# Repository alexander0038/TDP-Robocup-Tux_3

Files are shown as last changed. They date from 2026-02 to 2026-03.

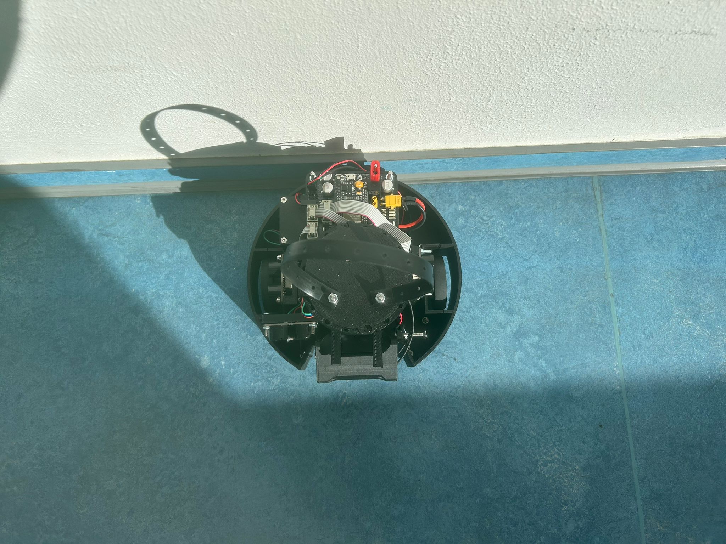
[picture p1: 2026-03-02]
Hardware/Robot pictures/Robot_picture_8.png

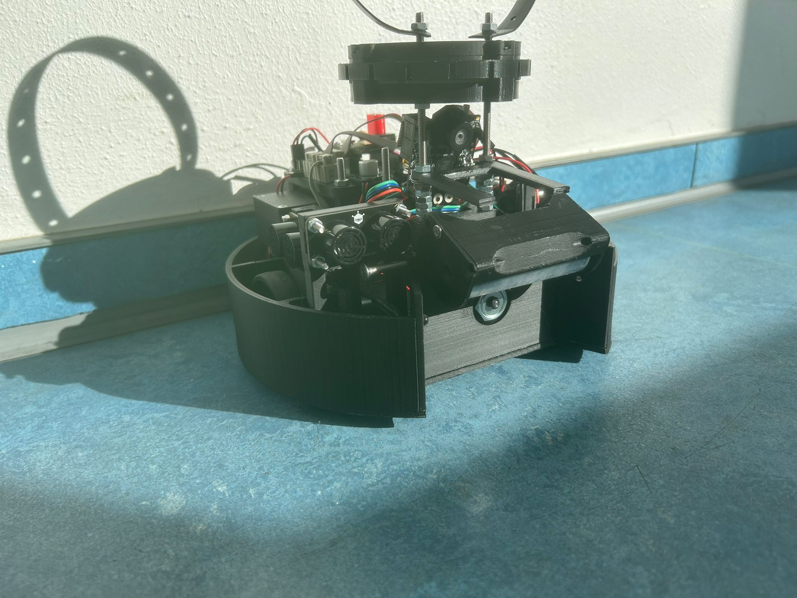
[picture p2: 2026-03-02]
Hardware/Robot pictures/Robot_picture_7.png

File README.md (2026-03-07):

# TEAM TUX_3 ROBOCUP PAGE

#### Email: tux3.gr@protonmail.com
#### Youtube: https://www.youtube.com/@Tux_3_gr

## General information about us:
We are Tux_3, a team from Rahden, a small town in North Rhine-Westphalia near Bielefeld. Our team consists of **Alexander Belov (Software, Team Captain)**, **Toni Schürmann (Software)**, **Max Harting (Hardware)** and **Henning Baumgartner (Hardware)**. We compete in the RoboCupJunior Soccer Entry League for the second time.

During our first time competing in RoboCup, we were separate teams: Tux_3 (Alexander and Henning) and Tux_4 (Toni and Max). Both teams made it into the top 5 and qualified for the German Open in Nuremberg. The competition in Nuremberg had strong opponents, so unfortunately we did not qualify for the European Championship.

However, these losses and wins did not make us lose motivation; instead, we merged into one team. We learned how to work together, and soon we managed to achieve second place in the Berlin qualification. Now we are preparing for the German Open in Cologne, hoping we can qualify for the European Championship.

---

### Where to find what:

#### Hardware:
- General information: `/Hardware/README.md`
- Chassis: `/Hardware/Chassis Pictures`
- Robot pictures: `/Hardware/Robot pictures`
- CAD programs: `/Hardware/CAD programs`

#### Software:
-  General information: `/software/README.md`
-  Program: `/software/Main`
-  Software for Sensors: `/software/Sensors`
-  Flowchart: `/software/Flowchart.png`
-  Strategy: `/software/Strategy.md`

#### Team:
- Team Description Paper: `/Tux_3_GO2026_tdp.pdf`
- Team picture: `/Tux_3.png`
- Team poster: `/Tux_3_GO2026_poster.pdf`

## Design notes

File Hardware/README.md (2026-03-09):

# Tux_3 Hardware Overview

This document describes the hardware architecture of the **Tux_3** RoboCupJunior Entry League robot.

## Mechanical Design

The chassis of Tux_3 is fully **3D-printed** and designed in **Autodesk Fusion**.  
It was built to be compact, stable, and easy to maintain.

Compared to the **LEGO-based robot used in the 2025 season**, the custom chassis provides significantly improved stability and durability.

## Drive System

Tux_3 uses a **two-motor drive system**.

- Pololu **25Dx48L MP 12V motors**
- Direct wheel mounting
- **Infineon IFX9201SG motor drivers**

This configuration provides strong acceleration, reliable turning, and a simple mechanical setup.

## Ball Handling and Kicking

### Dribbler

- Powered by a **GA16Y-050-CE motor**
- Maintains ball contact while driving

### Kicker

- Controlled by an **Infineon BTN8982TA** driver
- Mechanically aligned with the dribbler for consistent shots

## Sensors

Tux_3 uses several sensors for perception and navigation.

- **Vishay TSSP6038TR IR sensors** — ball detection  
- **CMPS14 compass** — orientation  
- **Pixy2 camera** — goal detection  
- **Light barrier** — ball possession detection  
- **DFRobot URM09** — distance measurement and wall detection

All sensors are integrated into the chassis to ensure stable readings.

## Electronics

The robot is controlled by an **ESP32 microcontroller**.

- **Infineon IFX9201SG** drivers control the drive motors
- **Infineon BTN8982TA** controls the kicker

The electronics layout is optimized for short cable paths and quick maintenance during competitions.

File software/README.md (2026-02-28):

# Software Overview — Tux_3

This folder contains the complete software for the Tux_3 RoboCupJunior Entry League robot.

## Architecture

The software is structured into the following modules:

- **Main** — Main control loop and initialization
- **Sensors** — Handles all sensor reading (DFRobot_URM09, compass)
- **Strategy** — High-level decision logic (attack/search/rescue)
  **→ Flowchart**

The ESP32 runs a main loop with approx. 100 Hz frequency. Within this loop:
1. Sensors are updated
2. State decisions are evaluated
3. Movement commands executed

## Dependencies

- CoRoSoN Software (https://github.com/ItzJannis/CoRoSoN-Package_Draft)
- ESP32 Arduino Core
- Pixy2 library
- Motor driver interfaces

## How to Run

1. Open in Arduino IDE
2. Select ESP32 board
3. Upload `main.ino`

## Logic Summary

The software implements a state-based decision system:
- **GET_BALL**
- **SEARCH_FOR_ENEMY_GOAL**
- **TURN_TO_ENEMY_GOAL**
- **DRIVE_TOWARDS_GOAL**
- **RESCUE**

Each state has its own behavior function (see strategy.cpp).

## Example Code Snippets

```cpp
if (irRing.BallSeen) {
    currentState = GET_BALL;
}

if (stuck) {
    currentState = RESCUE;
}

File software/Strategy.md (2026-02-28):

# Tux_3 — Strategy Overview

This document describes the high-level strategy and decision-making system of Team Tux_3's RoboCupJunior Soccer Entry League robot. It explains how the robot selects actions during a match, reacts to dynamic game conditions, and implements basic tactical behaviors.

---

## 1. Control Architecture

The robot's software is organized around a **main control loop running at approximately 100 Hz**, combined with modular tasks for:

- Sensor data acquisition  
- Motion control  
- Decision-making and tactical strategy  
- Rescue routines (stuck detection and recovery)

The strategy module is responsible for deciding the robot's behavior based on sensor inputs and match conditions.

---

## 2. High-Level States

The robot operates according to a **state-based system**, switching between the following main states:

1. **GET_BALL**  
   - The robot searches for the ball using infrared sensors (TSSP6038TR).  
   - If the ball is detected, the roboter will drive towards it.
  
2. **BACK_TO_OWN_GOAL**
   - If the robot doesn't see the ball, it turns to towards the enemy goal and quickly drives backwards.
  
3. **SEACH_FOR_ENEMY_GOAL**
   - The robot searches for the goal, using the Pixy camera.

4. **TURN_TO_ENEMY_GOAL**  
   - When the robot detects the goal: turn towards it.

5. **DRIVE_TOWARDS_GOAL**  
   - If the robot is turned directly to the goal, it drives forward.
   - If the robot isn't directly turned toward the goal it uses the Ultrasonic Sensors (DFRobot_URM09) to correct itself to the correct direction.

6. **RESCUE**  
   - If the robot detects that it is stuck (via sensor readings or lack of movement), a recovery routine is triggered.  
   - This includes reversing, turning, and repositioning to continue play.
  
---

## 3. Decision Flow

The robot continuously evaluates sensor inputs to determine:

- Ball detection status  
- Obstacle proximity and collisions  
- Robot orientation  
- Field boundaries  

Decisions are made in the following order:

1. Check if **stuck** → trigger RESCUE if necessary  
2. Ball not seen → switch to BACK_TO_OWN_GOAL
3. Detect ball → switch to GET_BALL
4. Check goal visibility → switch to SEARCH_FOR_ENEMY_GOAL  
5. Goal found → switch to  TURN_TO_ENEMY_GOAL
6. Directly turned to enemy goal → switch to DRIVE_TOWARDS_GOAL

This priority ensures the robot always reacts to the most critical situation first.

---

## 4. Sensor Integration

- **IR Ball Sensors (TSSP6038TR):** Primary detection of ball position  
- **Pixy2 Camera:** Confirmation of ball and goal position  
- **Compass (CMPS14):** Orientation stabilization for accurate approach and shooting  
- **Light barrier:** Detection of ball possession in the dribbler
- **Ultrasonic Sensor(DFRobot_URM09):** Detection of the distance 

The strategy module fuses these inputs to maintain reliable state transitions and tactical behavior.

---

## 5. Team Considerations

The strategy was designed to be:

- **Simple but effective**: Ideal for Entry League robots with limited processing power  
- **Robust**: Handles unexpected collisions and field dynamics  
- **Modular**: Easy to adjust parameters or add future tactics  

The state-based approach allows the robot to perform consistently in matches, while also making its behavior understandable to judges during interviews and poster presentations.

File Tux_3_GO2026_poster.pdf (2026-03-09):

\

\

\

\

The robot was collaboratively developed and built by all team members. The goal was to create a functional and competitive 1-vs-1 entry robot capable of autonomously collecting the ball, controlling it, and shooting it into the goal.

The system includes a curcit board, a ball sensor for object detection, two drive motors, three ultrasonic sensors for distance measurement, a dribbler for ball control, a PixyCam for goal detection, two lightbarriers for object detection and a kicker for precise shooting. A bill of materials for the main components can be found at the roboter description .

The construction process was carried out chronologically in several stages. First, the Chase and mounting brackets were manufactured using 3D printing. The material we are using for our robot is PLA+

. Afterwards, we installed the ball sensor, two ultrasonic sensors, the motors, two lightbarriers and the dribbler. Following our participation in the Berlin Open 2026, the system was further improved: a third ultrasonic sensor, a PixyCam, a kicker, and a new Chase were added to enhance overall performance.

These were the key decisions we made during the development of our robot:
- A front-facing \_/-shaped opening improves ball intake and enables faster and more stable ball control through the dribbler.
- The retrofitted kicker addresses previously identified weaknesses in goal finishing and now allows for direct and controlled shooting.
- Two laterally positioned ultrasonic sensors ensure more precise alignment with the opponent’s goal and support stable driving direction.

The total development and construction time was approximately ten months, the overall cost of the robot amounts to €310, and we used the programming language C++ for programming.

We are four students from the Gymnasium Rahden, a small town in North Rhine-Westphalia near Bielefeld. We go to two different classes. Despite this separation at school, we are united by a close friendship and a shared interest in robotics. Almost two years ago, we joined our school’s robotics club. Since then, robotics has become an integral part of our lives, as we not only work in the club but also dedicate time on weekends and during holidays.

After an initial training phase in which we learned basic programming commands, we developed a strong interest in the practical implementation of technical concepts. During this time, we also learned a great deal about how to divide tasks effectively. As we progressed, we designed and programmed our first LEGO robot. In 2025, we initially competed as two separate teams at the Berlin Open. There, we achieved remarkable results: one team secured second place, while the other finished fourth. These performances qualified us for the German Open 2025, where we placed eighth and thirteenth.

In this school year, we expanded our skills particularly in the field of additive manufacturing (3D printing) as well as in hardware
development. In addition, we decided to merge our two teams in order to achieve a better overall result and to combine our strengths. This collaboration led to the construction of a high-performance robot for the Berlin Open 2026, where we once again achieved second place.

For the German Open 2026, we worked even harder compared to the previous year and are now aiming to qualify for the Europe Open in Vienna. Regardless of the outcome, we are proud of what we have already achieved.

drive motors:
Pololu 25Dx48L
MP 12V
(on both sides)

dribbler: GA16Y-050-CE

ultrasonic sensor:
DFRobot

_

URM09
(on both sides)

# TUX

_

3

# Team

From left to Right:
Alexander Belov (Software and Team Captain)
Toni Schürmann (Software)
Max Harting (Hardware)
Henning Baumgartner (Hardware)
Abstract | Hardware

# Software

# Our GitHub

# Training video

# Our YouTube

circuit board,
ball sensor and
compass sensor
(CoRoSoN-Kit)

camera:Pixy 2

lightbarrier (on both sides) | kicker: Solenoid

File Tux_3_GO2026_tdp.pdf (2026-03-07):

## TEAM DESCRIPTION PAPER

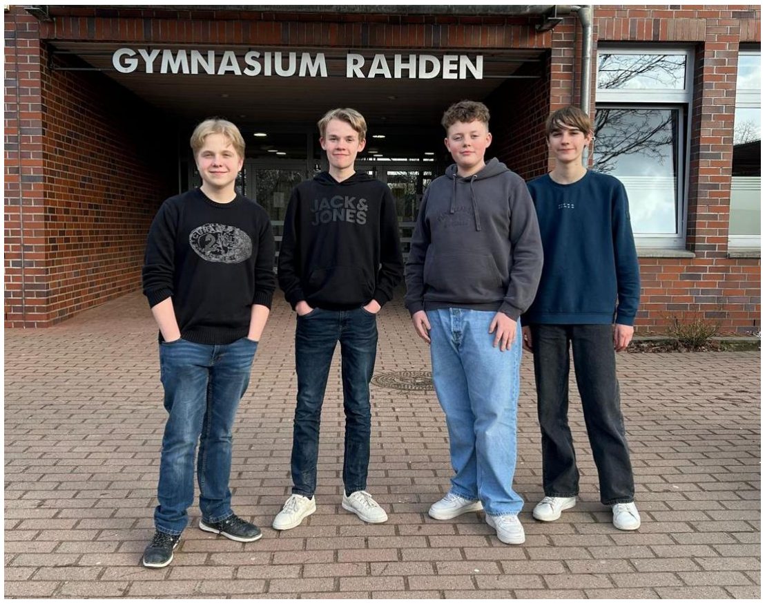
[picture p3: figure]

Team Tux_3 (from left to right: Alexander Belov (Team-Captain), Toni Schürmann, Max Harting, Henning Baumgartner)

Email: tux3.gr@protonmail.com

GitHub: https://github.com/alexander0038/TDP-Robocup-Tux_3/

Short Team Description

We, Tux_3, compete in the RoboCupJunior Soccer Entry League and were formed in 2026 by merging two previously independent teams.

In the 2025 season, the members competed separately as Tux_3 (Alexander and Henning) and Tux_4 (Max and Toni), both using LEGO-based robots. At the Berlin qualification tournament, Tux_3 achieved 2nd place and Tux_4 achieved 4th place. Both teams qualified for the German Championship in Nuremberg, where Tux_3 finished 8th (one match away from European qualification) and Tux_4 finished 13th.

In 2026, the two teams combined their experience and formed a single team under the name Tux_3, redesigning the robot with fully custom 3D-printed components. At the Berlin qualification tournament 2026, the new team achieved 2nd place.

Short Robot Description

The Tux_3 robot is a custom-built RoboCupJunior Entry League soccer robot designed for reliability, robustness, and continuous improvement. After competing with LEGO-based robots in 2025, the team fully redesigned the system for the 2026 season using custom 3D-printed components and a self-developed electronic architecture.

The robot is based on a two-motor differential drive system with integrated ball control and goal detection mechanisms. The overall design focuses on mechanical stability, precise ball handling, and structured decision-making during matches.

Hardware

Our hardware is based on the CoRoSoN-Kit (https://github.com/ItzJannis/CoRoSoN-Package_Draft). (https://github.com/ItzJannis/CoRoSoN-Package_Draft)

Drive System

- 2× Pololu 25Dx48L MP 12V motors
- Infineon IFX9201SG motor drivers

Ball Handling

- GA16Y-050-CE motor for dribbler
- Infineon BTN8982TA driver for kicker
- Light barrier for ball possession detection

Sensors

- Vishay TSSP6038TR infrared sensors for ball detection
- CMPS14 compass module for orientation stabilization
- Pixy2 camera for goal detection
- DFRobot_URM09 Ultrasonic sensors for distance measurement and wall correction

Electronics

- ESP32 microcontroller
- Custom wiring and structured component layout
- 3D-printed chassis designed in Autodesk Fusion

Software

The software is structured around a main control loop running on the ESP32. The system separates sensor acquisition, decision logic, and motor control into modular components. Our program is based on the CoRoSoN-Kit (https://github.com/ItzJannis/CoRoSoN-Package_Draft). (https://github.com/ItzJannis/CoRoSoN-Package_Draft)

Key characteristics:

- State-based decision logic:

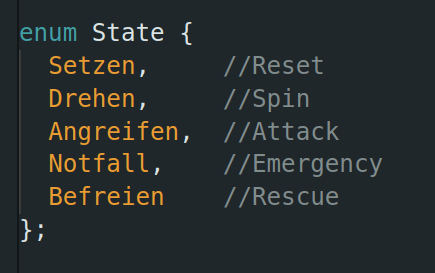
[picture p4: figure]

- Ball tracking using infrared sensors
- PID Control for motor control:

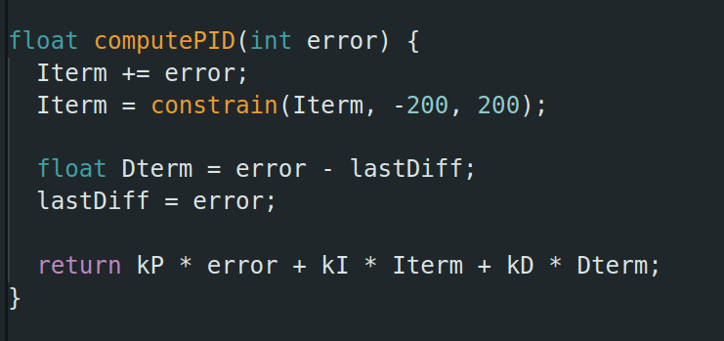
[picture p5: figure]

- Goal alignment using camera and compass
- Custom stuck-detection and recovery behavior:

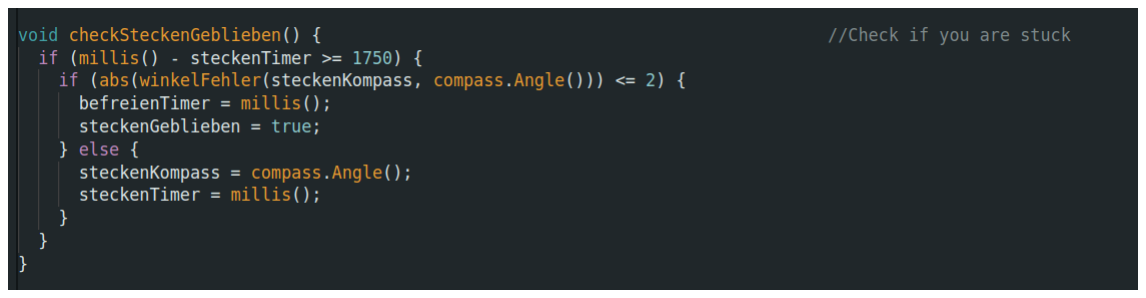
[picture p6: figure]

- Robot correction using ultrasonic feedback

The software was developed with a focus on maintainability, clarity, and match robustness.

Challenges During the Season

During the transition from LEGO to a fully custom 3D-printed robot, several challenges were encountered:

1. Mechanical Stability:
Early prototypes suffered from structural weaknesses and misalignment in the dribbler system.
2. Different Programming Languages:
We started with the programming language NXC, which translates to “Not exactly C”, and later switched to C/C++.
3. Sensor Calibration:
Reliable ball detection and consistent compass readings required extensive testing and calibration.
4. Drive Precision:
Achieving accurate turning and goal alignment without omni wheels required significant tuning of motor control.

Challenges Successfully Mastered

- Structural redesign improved mechanical robustness.
- Stable ball control was achieved through optimized dribbler positioning.
- Sensor placement and filtering significantly increased detection reliability.
- Stuck-detection logic improved match recovery performance.
- Team collaboration improved after merging two former teams into one unified structure.

These improvements led to a 2nd place finish at the 2026 Berlin qualification tournament.

Future Plans

For the next season, the team plans to:

- Compete in Robocup Junior Soccer Lightweight 1v1
- Learn more about the hardware
- Deepen our knowledge about programming
- Improve our ability to analyze and find mistakes in hardware and software faster
- Improve teamwork even further (if ’s even possible)

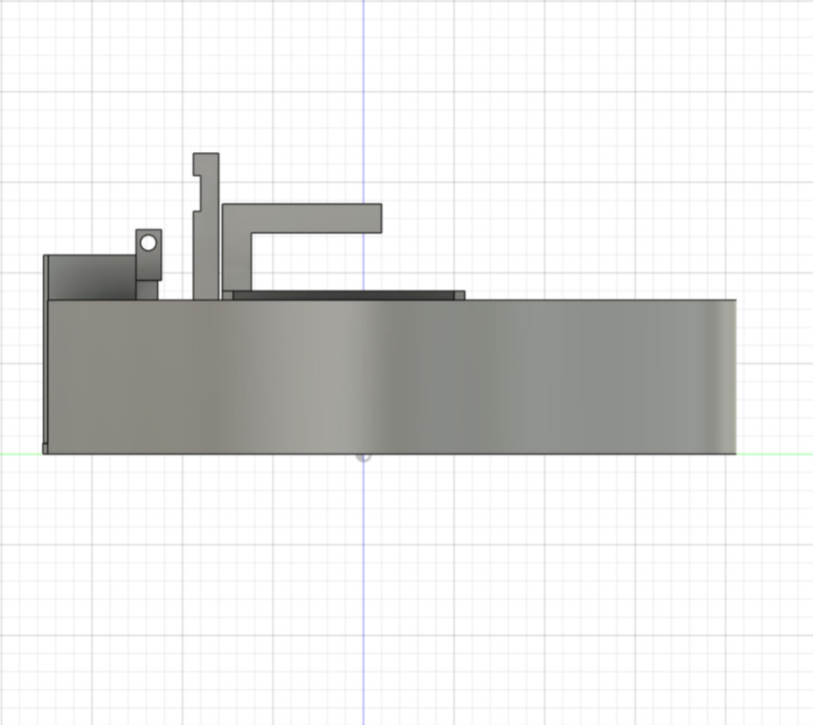
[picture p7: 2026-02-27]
Hardware/Chassis Pictures/Chassis_3.png

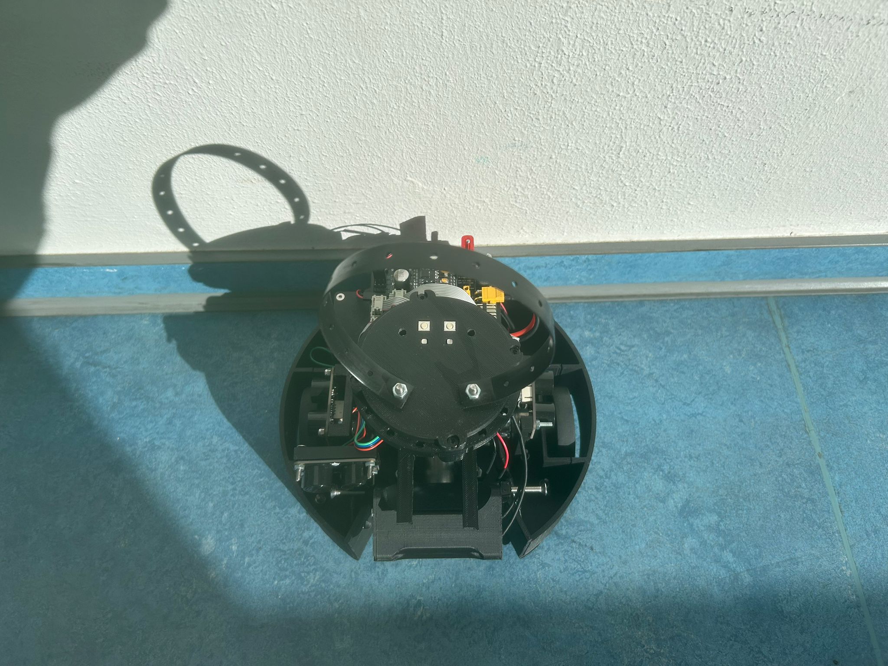
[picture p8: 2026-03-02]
Hardware/Robot pictures/Robot_picture_4.png

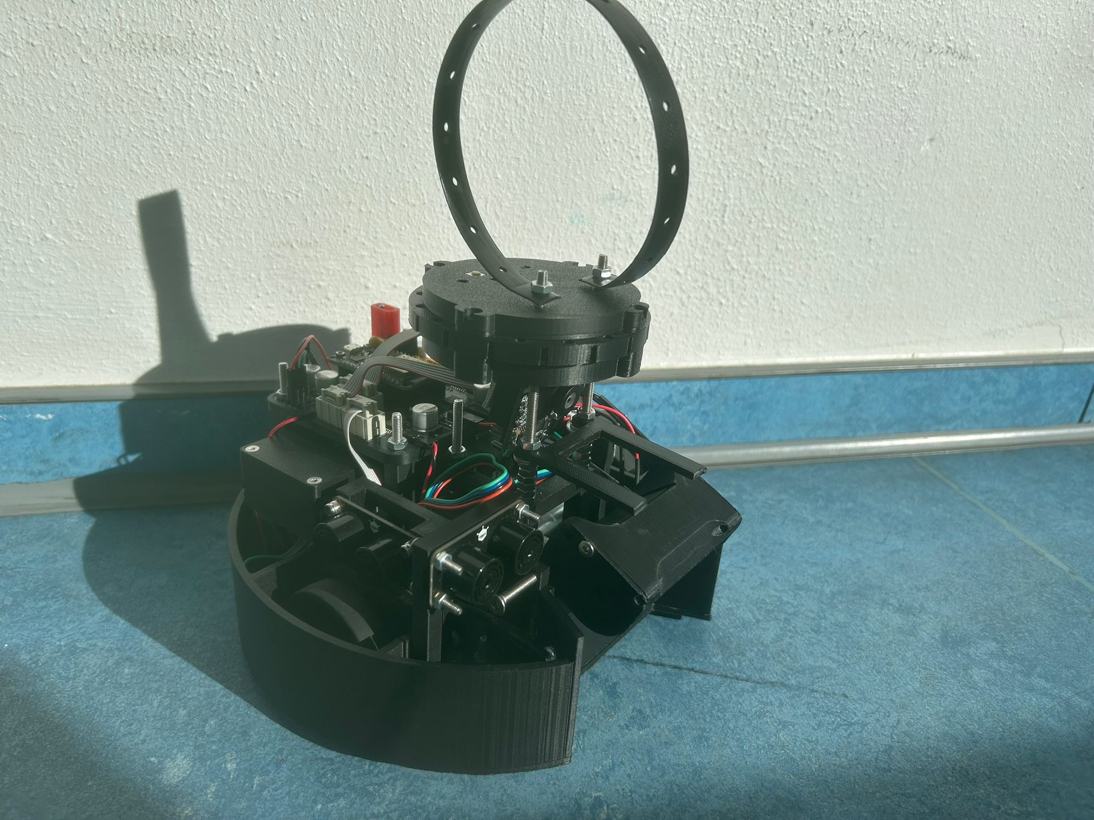
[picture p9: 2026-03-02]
Hardware/Robot pictures/Robot_picture_1.png

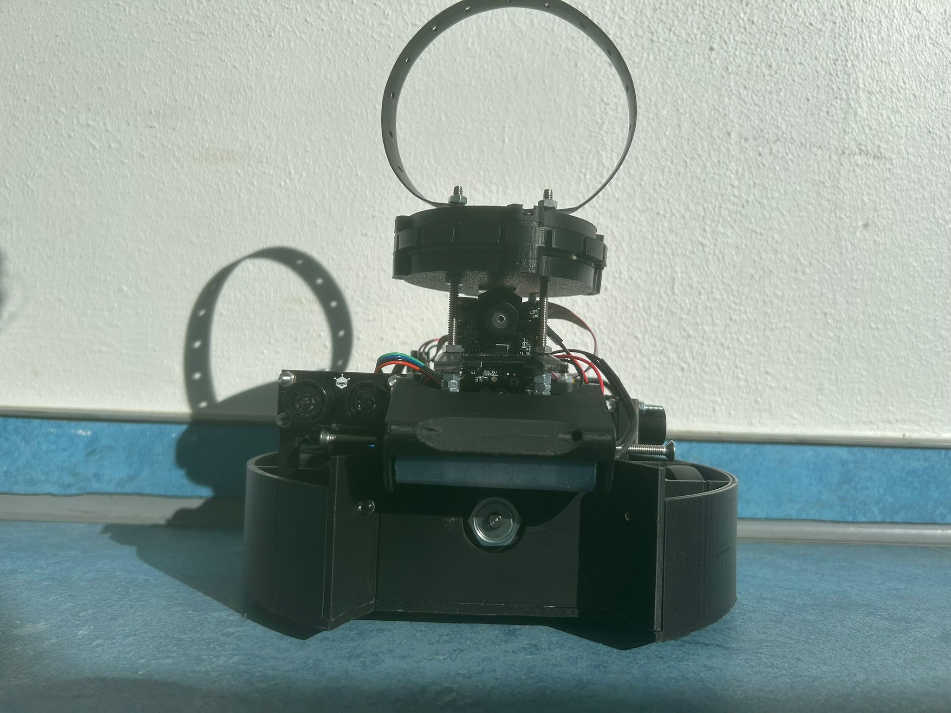
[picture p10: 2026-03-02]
Hardware/Robot pictures/Robot_picture_6.png

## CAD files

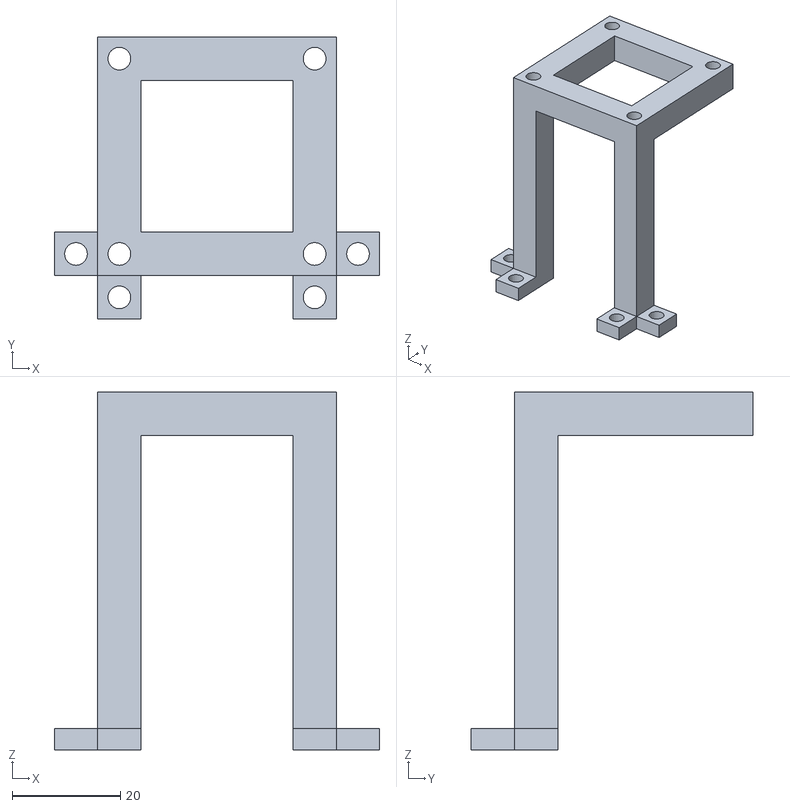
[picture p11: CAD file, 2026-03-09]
Hardware/CAD programs/Ballsensor mount.stl
60.0 x 52.0 x 66.0

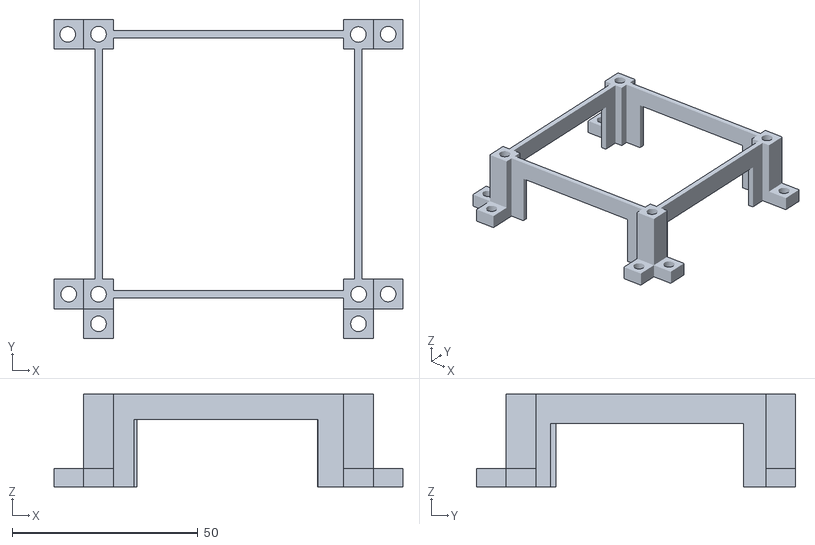
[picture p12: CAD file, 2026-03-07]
Hardware/CAD programs/Board mount.stl
94.0 x 86.0 x 25.0

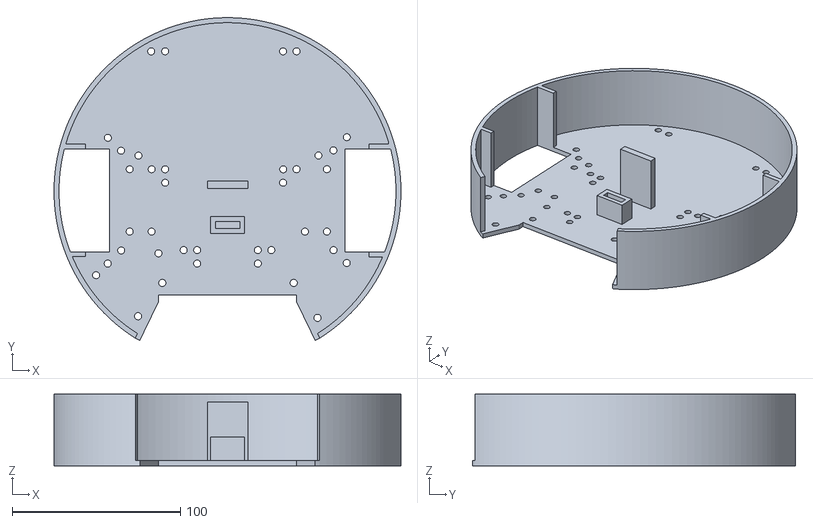
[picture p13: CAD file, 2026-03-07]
Hardware/CAD programs/Raw Chassis.stl
206.0 x 191.5 x 42.5

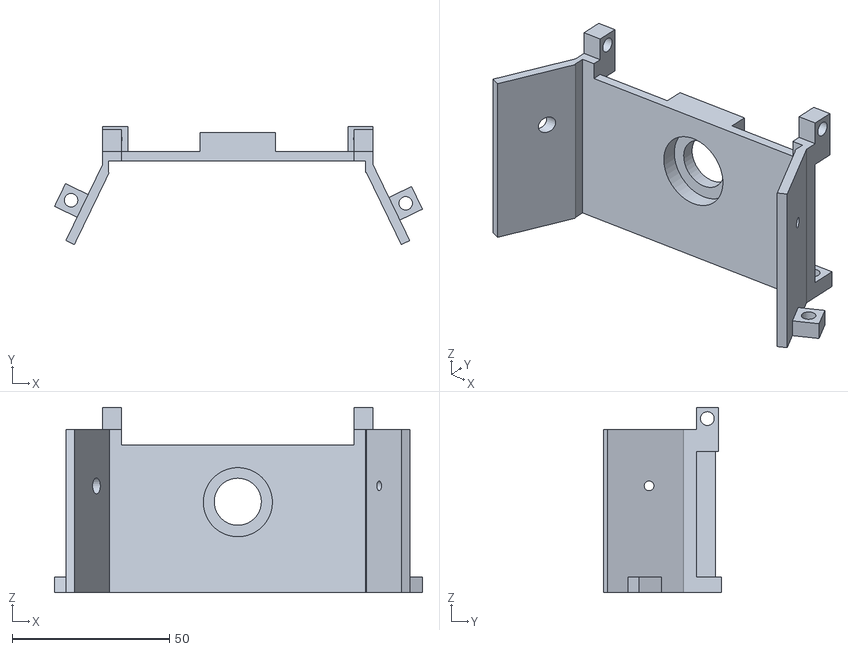
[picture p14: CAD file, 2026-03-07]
Hardware/CAD programs/Front (Dribbler_ Kicker_ Lightbarrier).stl
117.1 x 37.7 x 59.0

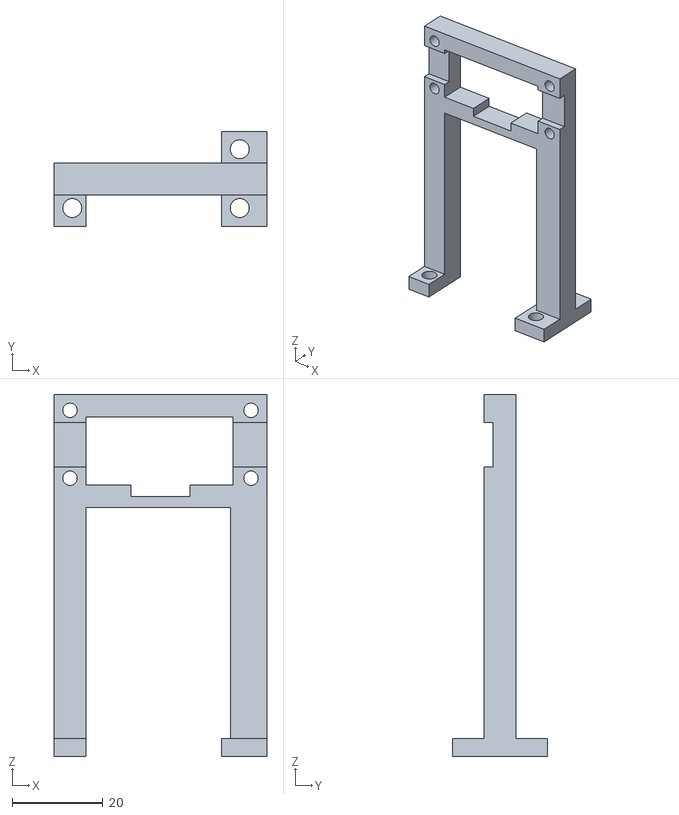
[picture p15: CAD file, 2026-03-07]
Hardware/CAD programs/Ultrasonic-Sensor (x3).stl
47.0 x 21.0 x 80.0

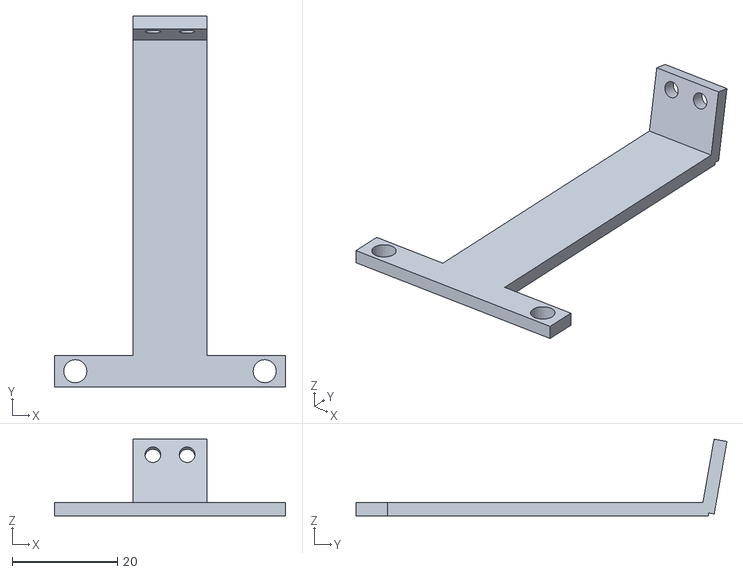
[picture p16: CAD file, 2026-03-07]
Hardware/CAD programs/Pixy mount.stl
44.0 x 70.5 x 14.6

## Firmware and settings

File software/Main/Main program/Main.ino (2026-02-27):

#include <Arduino.h>
#include "CoRoSoN_Main.h"
#include "CoRoSoN_IR-Ring.h"
#include "CoRoSoN_Compass.h"
#include "CoRoSoN_Pixy.h"
#include <elapsedMillis.h>
#include "DFRobot_URM09.h"

#define winkelToleranz 10
#define drehToleranz 5
#define AVS 65
#define MIS 30
#define MAS 90

float kP = 0.8;
float kI = 0.01;
float kD = 2.0;
float Iterm = 0;

byte fehlschlag = 0;
byte durchlauf = 0;
byte eckenStep = 0;
byte gesetzt = 0;

unsigned long startTimer;
unsigned long timer;
unsigned long steckenTimer;
unsigned long befreienTimer;

bool kompassGerichtet = false;
bool sucheBall = false;
bool machTor = false;
bool timerGesetzt = false;
bool varianteEins = false;
bool modusGesetzt = false;
bool varianteZwei = false;
bool zurueckStandBy = false;
bool steckenGeblieben = false;
bool lgroeßer = false;
bool rgroeßer = false;
bool startGesetzt = false;
bool IsInGame = false;
bool kickenErlaubt = false;
bool pixyVorher = false;
bool pixyJetzt = false;
bool torNichtGefunden = false;
bool befreit = false;

int speed = 0;
int steckenKompass = 0;
int eigenesTor = 0;
int ecke1 = 0;
int ecke2 = 0;
int GegnerTor = 0;
int lastL = 0;
int lastR = 0;
int Comp;
int Dir;
int rUS;
int lUS;
int lastDiff = 0;
int richtung = 0;

enum State {
  Setzen,
  Drehen,
  Angreifen,
  Notfall,
  Befreien
};

State step = Setzen;
IRRing irRing(I2C_ADD_IR);
Compass compass(I2C_ADD_Compass);
Pixy pixy(I2C_ADD_PIXY, 1, 2);

elapsedMillis buttonDeadTime = 0;
elapsedMillis angriffStecken = 0;
elapsedMillis kickenZeit = 0;
elapsedMillis checkSuche = 0;

DFRobot_URM09 URM09_R;
DFRobot_URM09 URM09_L;
DFRobot_URM09 URM09_V;


void setup() {

  if (!URM09_R.begin(0x12)) {
    Serial.println("I2C device number error R");
    delay(1000);
  }
  if (!URM09_L.begin(0x11)) {
    Serial.println("I2C device number error L");
    delay(1000);
  }
  if (!URM09_V.begin(0x13)) {
    Serial.println("I2C device number error L");
    delay(1000);
  }

  URM09_R.setModeRange(MEASURE_MODE_AUTOMATIC, MEASURE_RANG_500);
  delay(100);

  URM09_L.setModeRange(MEASURE_MODE_AUTOMATIC, MEASURE_RANG_500);
  delay(100);

  pinMode(17, OUTPUT);

  delay(500);
  SetBoardLEDColor(LEFT, BLUE);
  SetBoardLEDColor(RIGHT, BLUE);



  CoRoSoN_Init();
  pixy.Init();

  SetI2CLEDColor(I2C_MODULE_1, LEFT, RED);
  SetI2CLEDColor(I2C_MODULE_1, RIGHT, RED);

  delay(200);
  SetBoardLEDColor(LEFT, GREEN);
  SetBoardLEDColor(RIGHT, GREEN);
  delay(200);
  SetBoardLEDColor(LEFT, RED);
  SetBoardLEDColor(RIGHT, RED);
  delay(200);
  SetBoardLEDColor(LEFT, YELLOW);
  SetBoardLEDColor(RIGHT, YELLOW);
  delay(200);
  SetBoardLEDColor(LEFT, BLUE);
  SetBoardLEDColor(RIGHT, BLUE);
  delay(200);
  SetBoardLEDColor(LEFT, CYAN);
  SetBoardLEDColor(RIGHT, CYAN);
  delay(200);
  SetBoardLEDColor(LEFT, MAGENTA);
  SetBoardLEDColor(RIGHT, MAGENTA);
  delay(200);
  SetBoardLEDColor(LEFT, WHITE);
  SetBoardLEDColor(RIGHT, WHITE);
  delay(200);
  SetBoardLEDColor(LEFT, OFF);
  SetBoardLEDColor(RIGHT, OFF);
  delay(500);
}

void kick() {
  digitalWrite(17, HIGH);
  delay(30);
  digitalWrite(17, LOW);
}


bool lightbarrierTriggered() {
  int val = analogRead(4);

  if ((val > 2300 || val < 2100) && abs(irRing.BallDirection()) < 5)
    SetI2CLEDColor(I2C_MODULE_1, LEFT, GREEN);
  else
    SetI2CLEDColor(I2C_MODULE_1, LEFT, RED);

  return ((val > 2300 || val < 2100) && abs(irRing.BallDirection()) < 5);
}

void drive(int speed, int rotation) {
  int MaxSpeed = ABS(speed) + ABS(rotation);
  if (MaxSpeed > 100) {
    speed = (speed * 100) / MaxSpeed;
    rotation = (rotation * 100) / MaxSpeed;
  }
  int spd1 = rotation - speed;
  int spd2 = rotation + speed;
  DIRECTION dir1 = (spd1 >= 0 ? FORWARD : BACKWARD);
  DIRECTION dir2 = (spd2 >= 0 ? FORWARD : BACKWARD);
  SetMotor(MOTOR_1, dir1, spd1);
  SetMotor(MOTOR_2, dir2, spd2);
}

void standby() {
  if (zurueckStandBy == true) {
    SetI2CLEDColor(I2C_MODULE_1, LEFT, GREEN);
    SetI2CLEDColor(I2C_MODULE_1, RIGHT, GREEN);
  }

  SetMotor(MOTOR_1, FORWARD, 0);
  SetMotor(MOTOR_2, FORWARD, 0);
  SetMotor(MOTOR_3, FORWARD, 0);
  SetMotor(MOTOR_4, FORWARD, 0);

  if (irRing.BallSeen()) {
    if (ABS(irRing.BallDirection()) < 3) {
      SetBoardLEDColor(LEFT, GREEN);
    } else if (ABS(irRing.BallDirection()) < 15 && ABS(irRing.BallDirection()) >= 3) {
      SetBoardLEDColor(LEFT, CYAN);
    } else {
      SetBoardLEDColor(LEFT, BLUE);
    }
  } else {
    SetBoardLEDColor(LEFT, RED);
  }

  if (compass.Angle() < 90) {
    SetBoardLEDColor(RIGHT, BLUE);
  } else if (compass.Angle() >= 90 && compass.Angle() < 180) {
    SetBoardLEDColor(RIGHT, CYAN);
  } else if (compass.Angle() >= 180 && compass.Angle() < 270) {
    SetBoardLEDColor(RIGHT, MAGENTA);
  } else {
    SetBoardLEDColor(RIGHT, YELLOW);
  }

  if (zurueckStandBy == true) {
    if (buttonDeadTime < 500) {
      SetI2CLEDColor(I2C_MODULE_1, LEFT, RED);
      SetI2CLEDColor(I2C_MODULE_1, RIGHT, RED);
    } else {
      zurueckStandBy = false;
      SetI2CLEDColor(I2C_MODULE_1, LEFT, GREEN);
      SetI2CLEDColor(I2C_MODULE_1, RIGHT, GREEN);
    }
  }

  if (zurueckStandBy == false) {
    if (ButtonIsPressed(I2C_MODULE_1, LEFT)) {
      if (buttonDeadTime > 500) {
        SetI2CLEDColor(I2C_MODULE_1, RIGHT, GREEN);
        compass.Update();
        GegnerTor = compass.Angle();
        eigenesTor = (GegnerTor - 180 + 360) % 360;
        ecke1 = (GegnerTor + 45) % 360;
        ecke2 = (GegnerTor - 45 + 360) % 360;
        buttonDeadTime = 0;
      }
    }

    if (ButtonIsPressed(I2C_MODULE_1, RIGHT)) {
      if (buttonDeadTime > 500) {
        IsInGame = true;
        buttonDeadTime = 0;
        SetBoardLEDColor(RIGHT, OFF);
        SetBoardLEDColor(LEFT, OFF);
        SetI2CLEDColor(I2C_MODULE_1, LEFT, OFF);
        SetI2CLEDColor(I2C_MODULE_1, RIGHT, OFF);
      }
    }
  }
}

int filterUS(int neu, int alt) {
  if (alt == 0) return neu;
  if (neu <= 0 || neu > 300) return alt;
  if (abs(neu - alt) > 25) return alt + (neu - alt) / 4;
  return neu;
}

int winkelFehler(int soll, int ist) {
  int diff = soll - ist;
  if (diff > 180) diff -= 360;
  if (diff < -180) diff += 360;
  return diff;
}

void checkSteckenGeblieben() {
  if (millis() - steckenTimer >= 1750) {
    if (abs(winkelFehler(steckenKompass, compass.Angle())) <= 2) {
      befreienTimer = millis();
      steckenGeblieben = true;
    } else {
      steckenKompass = compass.Angle();
      steckenTimer = millis();
    }
  }
}

void checkComp() {
  compass.Update();
  Comp = compass.Angle();
}

void checkDir() {
  irRing.Update();
  Dir = irRing.BallDirection();
}

int drehSpeedAusBall(int ballDir) {
  int absDir = abs(ballDir);

  absDir = constrain(absDir, 4, 11);

  return map(absDir, 4, 11, 35, 50);
}

int fahrSpeedzuBall(int Entfehrnung) {
  int absDis = abs(Entfehrnung);

  absDis = constrain(absDis, 15, 50);

  return map(absDis, 15, 50, 58, 90);
}

int drehSpeedAngriff(int compass, int drehZiel) {
  int fehler = winkelFehler(drehZiel, compass);
  int absFehler = abs(fehler);

  absFehler = constrain(absFehler, 0, 90);

  if (absFehler < drehToleranz / 2) return 0;

  return map(absFehler, 0, 90, 25, 70);
}

void ballVerfolgung() {
  checkDir();
  checkSteckenGeblieben();

  if (irRing.BallDirection() >= -1 && irRing.BallDirection() <= 1) {
    byte Distanz = irRing.BallDistance();
    int forwardSpeed = fahrSpeedzuBall(Distanz);
    SetMotor(MOTOR_1, FORWARD, forwardSpeed);
    SetMotor(MOTOR_2, FORWARD, forwardSpeed);
    SetI2CLEDColor(I2C_MODULE_1, RIGHT, GREEN);
  } else if (irRing.BallDirection() > 3 && irRing.BallDirection() <= 11) {
    speed = drehSpeedAusBall(Dir);
    SetMotor(MOTOR_1, BACKWARD, speed);
    SetMotor(MOTOR_2, FORWARD, speed);
    SetI2CLEDColor(I2C_MODULE_1, RIGHT, CYAN);
  } else if (irRing.BallDirection() < -3 && irRing.BallDirection() >= -11) {
    speed = drehSpeedAusBall(Dir);
    SetMotor(MOTOR_2, BACKWARD, speed);
    SetMotor(MOTOR_1, FORWARD, speed);
    SetI2CLEDColor(I2C_MODULE_1, RIGHT, CYAN);
  } else if (irRing.BallDirection() == -2 || irRing.BallDirection() == -3) {
    SetMotor(MOTOR_1, FORWARD, 28);
    SetMotor(MOTOR_2, FORWARD, 43);
    SetI2CLEDColor(I2C_MODULE_1, RIGHT, WHITE);
  } else if (irRing.BallDirection() == 2 || irRing.BallDirection() == 3) {
    SetMotor(MOTOR_1, FORWARD, 28);
    SetMotor(MOTOR_2, FORWARD, 43);
    SetI2CLEDColor(I2C_MODULE_1, RIGHT, WHITE);
  } else if (abs(irRing.BallDirection()) <= 12 && abs(irRing.BallDirection()) <= 16) {
    SetMotor(MOTOR_1, BACKWARD, 60);
    SetMotor(MOTOR_2, BACKWARD, 60);
  } else if (abs(irRing.BallDirection()) >= 17) {
    SetMotor(MOTOR_1, BACKWARD, 85);
    SetMotor(MOTOR_2, BACKWARD, 85);
  }
}

void angriffBefreien() {
  int fehler = winkelFehler(richtung, compass.Angle());

  if (angriffStecken >= 10000 && angriffStecken <= 11000) {
    float korr = computePID(fehler);
    korr = constrain(korr, -10, 10);

    byte baseSpeed = 90;

    int left = constrain(baseSpeed - korr, 0, 100);
    int right = constrain(baseSpeed + korr, 0, 100);

    SetMotor(MOTOR_1, BACKWARD, left);
    SetMotor(MOTOR_2, BACKWARD, right);
  }
}

void torFinden() {
  int linksSuchen = (GegnerTor + 20) % 360;
  int rechtsSuchen = (GegnerTor - 20 + 360) % 360;
  static byte check = 0;

  if (checkSuche >= 6000) {
    torNichtGefunden = true;
  }

  if (check == 0) {
    if (abs(winkelFehler(linksSuchen, compass.Angle())) >= 3) {
      SetMotor(MOTOR_2, BACKWARD, 50);
      SetMotor(MOTOR_1, FORWARD, 50);
    } else check = 1;
  } else if (check == 1) {
    if (abs(winkelFehler(rechtsSuchen, compass.Angle())) >= 3) {
      SetMotor(MOTOR_2, FORWARD, 50);
      SetMotor(MOTOR_1, BACKWARD, 50);
    } else check = 0;
  }
}

float computePID(int error) {
  Iterm += error;
  Iterm = constrain(Iterm, -200, 200);

  float Dterm = error - lastDiff;
  lastDiff = error;

  return kP * error + kI * Iterm + kD * Dterm;
}

void torSuche() {
  //Möglicher Fehler durch nicht gesetzte Zeitbegrenzung bei Befreiung
  static bool lgroesser = false;
  static bool rgroesser = false;
  static bool sollGesetzt = false;
  static unsigned long befreienTimer = 0;
  bool lb = lightbarrierTriggered();

  pixyJetzt = pixy.OwnGoalSeen();

  if (pixyJetzt && !pixyVorher && lb && !befreit) {
    step = Befreien;
    befreienTimer = millis();
    befreit = true;
  }

  //if(befreit) befreit = false;

  if (step == Setzen) {
    Iterm = 0;
    lastDiff = 0;
    lastL = 0;
    lastR = 0;
    step = Drehen;
    angriffStecken = 0;
    lgroesser = false;
    rgroesser = false;
    sollGesetzt = false;
    befreit = false;
    checkSuche = 0;
  }

  else if (step == Drehen) {
    checkComp();
    checkSteckenGeblieben();
    if (steckenGeblieben) return;

    int rawL = URM09_L.getDistance();
    int rawR = URM09_R.getDistance();
    lUS = filterUS(rawL, lastL);
    rUS = filterUS(rawR, lastR);
    lastL = lUS;
    lastR = rUS;

    int fehler = winkelFehler(GegnerTor, Comp);
    float pid = computePID(fehler);

    int maxUS = 150;
    lUS = constrain(lUS, 0, maxUS);
    rUS = constrain(rUS, 0, maxUS);

    int lReduktion = map(rUS, 0, 90, 0, 40);
    int rReduktion = map(lUS, 0, 90, 0, 40);

    int leftSpeed = AVS - pid - lReduktion;
    int rightSpeed = AVS + pid - rReduktion;

    int l = constrain(leftSpeed, MIS, MAS);
    int r = constrain(rightSpeed, MIS, MAS);

    SetMotor(MOTOR_1, FORWARD, l);
    SetMotor(MOTOR_2, FORWARD, r);

    if (abs(fehler) <= 7) {
      if (lUS > rUS) lgroesser = true;
      else rgroesser = true;
      angriffStecken = 0;
      step = Angreifen;
      Iterm = 0;
      lastDiff = 0;
      sollGesetzt = false;
    } else if (!lb) {
      sucheBall = true;
      machTor = false;
      rgroesser = false;
      lgroesser = false;
      sollGesetzt = false;
      angriffStecken = 0;
      step = Setzen;
      befreit = false;
      checkSuche = 0;
    }
  }

  else if (step == Angreifen) {
    if (!lb) {
      rgroesser = false;
      lgroesser = false;
      sucheBall = true;
      machTor = false;
      sollGesetzt = false;
      angriffStecken = 0;
      step = Setzen;
      kickenZeit = 0;
      befreit = false;
    }
    if (!torNichtGefunden) {
      if (angriffStecken > 11000) {
        angriffStecken = 0;
      } else if (angriffStecken >= 10000 && angriffStecken <= 11000) {
        angriffBefreien();
        steckenGeblieben = false;
      }

      if (pixy.GoalSeen()) {
        checkSuche = 0;
        if (!sollGesetzt) {
          compass.Update();
          richtung = compass.Angle();
          sollGesetzt = true;
        }

        int fehler = winkelFehler(richtung, compass.Angle());
        float korrCompass = computePID(fehler);
        korrCompass = constrain(korrCompass, -9, 9);

        int pixyDir = pixy.GoalDirection();
        float korrPixy = pixyDir * 6;
        korrPixy = constrain(korrPixy, -6, 6);

        float korrGesamt = korrCompass + korrPixy;
        korrGesamt = constrain(korrGesamt, -15, 15);

        byte baseSpeed = 85;

        int left = constrain(baseSpeed - korrGesamt, 70, 100);
        int right = constrain(baseSpeed + korrGesamt, 70, 100);

        SetMotor(MOTOR_1, FORWARD, left);
        SetMotor(MOTOR_2, FORWARD, right);

        if (kickenZeit >= 2000 && kickenErlaubt == true) {
          kick();
          kickenZeit = 0;
        }
      } else {
        sollGesetzt = false;
        kickenZeit = 0;
        torFinden();
      }
    } else {
      step = Notfall;
    }
  } else if (step == Notfall) {
    if (pixy.GoalSeen()) {
      step = Angreifen;
      kickenZeit = 0;
      checkSuche = 0;
      return;
    }

    checkSteckenGeblieben();
    if (steckenGeblieben) return;

    if (!lb) {
      rgroesser = false;
      lgroesser = false;
      sucheBall = true;
      machTor = false;
      step = Setzen;
      checkSuche = 0;
    }

    static int leftSpeed = 0;
    static int rightSpeed = 0;

    checkComp();
    int ist = Comp;

    int rawL = URM09_L.getDistance();
    int rawR = URM09_R.getDistance();
    lUS = filterUS(rawL, lastL);
    rUS = filterUS(rawR, lastR);
    lastL = lUS;
    lastR = rUS;

    if (lUS > rUS) lgroesser = true;
    else rgroesser = true;

    int fehler = winkelFehler(GegnerTor, ist);
    float pid = computePID(fehler);
    pid = constrain(pid, -8, 8);

    lUS = constrain(lUS, 0, 90);
    rUS = constrain(rUS, 0, 90);

    int lReduktion = map(lUS, 0, 90, 40, 0);
    int rReduktion = map(rUS, 0, 90, 40, 0);

    bool mittig = abs(lUS - rUS) <= 5;

    if (mittig && abs(fehler) <= winkelToleranz) {
      leftSpeed = 80;
      rightSpeed = 80;
    } else if (lgroesser) {
      leftSpeed = 70 + pid + lReduktion;
      rightSpeed = 70 - pid;
    } else if (rgroesser) {
      leftSpeed = 70 - pid;
      rightSpeed = 70 + pid + rReduktion;
    }

    int l = constrain(leftSpeed, 50, 95);
    int r = constrain(rightSpeed, 50, 95);

    SetMotor(MOTOR_1, FORWARD, l);
    SetMotor(MOTOR_2, FORWARD, r);

  } else if (step == Befreien) {
    if (millis() - befreienTimer <= 2000) {
      int fehler = winkelFehler(GegnerTor, compass.Angle());

      float korr = computePID(fehler);
      korr = constrain(korr, -10, 10);

      byte baseSpeed = 90;

      int left = constrain(baseSpeed - korr, 80, 100);
      int right = constrain(baseSpeed + korr, 80, 100);

      SetMotor(MOTOR_1, BACKWARD, left);
      SetMotor(MOTOR_2, BACKWARD, right);
    } else {
      step = Setzen;
      befreit = true;
    }
  }
  pixyVorher = pixy.OwnGoalSeen();
}

void game() {
  if (!pixy.OwnGoalSeen()) kickenErlaubt = true;
  else kickenErlaubt = false;

  int rawL = URM09_L.getDistance();
  int rawR = URM09_R.getDistance();

  lUS = filterUS(rawL, lastL);
  rUS = filterUS(rawR, lastR);

  lastL = lUS;
  lastR = rUS;

  checkComp();

  SetMotor(MOTOR_3, FORWARD, 100);

  if (!modusGesetzt && buttonDeadTime > 500) {
    SetI2CLEDColor(I2C_MODULE_1, LEFT, RED);
    SetI2CLEDColor(I2C_MODULE_1, RIGHT, RED);
    if (ButtonIsPressed(I2C_MODULE_1, LEFT) && !ButtonIsPressed(I2C_MODULE_1, RIGHT)) {
      varianteEins = true;
      startTimer = millis();
      modusGesetzt = true;
      buttonDeadTime = 0;
    } else if (ButtonIsPressed(I2C_MODULE_1, RIGHT) && !ButtonIsPressed(I2C_MODULE_1, LEFT)) {
      varianteZwei = true;
      modusGesetzt = true;
      buttonDeadTime = 0;
    }
  }

  if (varianteZwei) {
    varianteZ();
  } else if (varianteEins) {
    varianteE();
  }

  if (lUS > rUS + 5) SetBoardLEDColor(RIGHT, RED);
  else if(lUS <= rUS + 5 && rUS <= lUS + 5) SetBoardLEDColor(RIGHT, BLUE);
  else SetBoardLEDColor(RIGHT, GREEN);
}

void varianteE() /*variante Eins*/ {
  static int startWinkel;

  if (!startGesetzt) {
    compass.Update();
    startWinkel = compass.Angle();
    startTimer = millis();
    startGesetzt = true;
  }

  if (millis() - startTimer < 6500) {
    compass.Update();

    int fehler = winkelFehler(GegnerTor, compass.Angle());
    float korr = computePID(fehler);
    korr = constrain(korr, -25, 25);

    int baseSpeed = 100;

    int left = constrain(baseSpeed - korr, 75, 100);
    int right = constrain(baseSpeed + korr, 75, 100);

    SetMotor(MOTOR_1, FORWARD, left);
    SetMotor(MOTOR_2, FORWARD, right);
  } else {
    varianteEins = false;
    varianteZwei = true;
  }
}

void varianteZ() /*variante Zwei*/ {
  if (irRing.BallSeen()) {
    if (!(lightbarrierTriggered())) {
      sucheBall = true;
      machTor = false;
    } else {
      sucheBall = false;
      machTor = true;
    }

    if (sucheBall) {
      gesetzt = 0;
      step = Setzen;
      steckenGeblieben = false;
      ballVerfolgung();
    } else if (machTor) {
      if (gesetzt == 0) {
        timer = millis();
        gesetzt = 1;
      }
      torSuche();
    }

    if (steckenGeblieben && step != Angreifen) {
      checkComp();
      if (millis() - befreienTimer < 1000) {
        SetMotor(MOTOR_1, FORWARD, 100);
        SetMotor(MOTOR_1, FORWARD, 100);
      } else {
        steckenGeblieben = false;
        steckenKompass = compass.Angle();
        steckenTimer = millis();
      }
    }
  } else {
    checkComp();
    SetI2CLEDColor(I2C_MODULE_1, RIGHT, RED);

    int drehFehler = winkelFehler(GegnerTor, Comp);
    int speedB = drehSpeedAngriff(Comp, GegnerTor);
    float pid = computePID(drehFehler);
    pid = constrain(pid, -6, 6);
    int speedL = 80 - pid;
    int speedR = 80 + pid;

    if (abs(drehFehler) > 10) {
      if (drehFehler > 0) {
        SetMotor(MOTOR_1, BACKWARD, speedB);
        SetMotor(MOTOR_2, FORWARD, speedB);
      } else {
        SetMotor(MOTOR_1, FORWARD, speedB);
        SetMotor(MOTOR_2, BACKWARD, speedB);
      }
    } else {
      SetMotor(MOTOR_1, BACKWARD, speedL);
      SetMotor(MOTOR_2, BACKWARD, speedR);
    }
  }
}


void loop() {
  if (IsInGame) {
    game();

    if ((ButtonIsPressed(I2C_MODULE_1, LEFT) || ButtonIsPressed(I2C_MODULE_1, RIGHT)) && modusGesetzt == true) {
      if (buttonDeadTime > 500) {
        IsInGame = false;
        modusGesetzt = false;
        varianteEins = false;
        varianteZwei = false;
        zurueckStandBy = true;
        startGesetzt = false;
        step = Setzen;
        buttonDeadTime = 0;
        eckenStep = 0;
        befreit = false;
      }
    }
  } else {
    standby();
  }

  /*
  DEBUG_PRINT(irRing.BallSeen());
  DEBUG_PRINT(irRing.BallDirection());
  DEBUG_PRINT(irRing.BallDistance());
  DEBUG_PRINT(pixy.GoalSeen());
  DEBUG_PRINT(pixy.GoalDirection());
  DEBUG_PRINT(pixy.OwnGoalSeen());
  DEBUG_PRINT(pixy.OwnGoalDirection());
  */

  compass.Update();
  irRing.Update();
  pixy.Update();
  delay(5);
}

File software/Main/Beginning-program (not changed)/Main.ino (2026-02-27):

#include "CoRoSoN_Main.h"
#include "CoRoSoN_IR-Ring.h"
#include "CoRoSoN_Pixy.h"
#include <elapsedMillis.h>

IRRing irRing(I2C_ADD_IR);
Pixy pixy(I2C_ADD_PIXY, 1, 2);
bool IsInGame = false;
elapsedMillis buttonDeadTime = 0;

void setup() {
  CoRoSoN_Init();
  pixy.Init();

  delay(200);
  CoRoSoN_SetBoardLEDColor(LEFT , GREEN);
  CoRoSoN_SetBoardLEDColor(RIGHT, GREEN);
  delay(200);
  CoRoSoN_SetBoardLEDColor(LEFT , RED);
  CoRoSoN_SetBoardLEDColor(RIGHT, RED);
  delay(200);
  CoRoSoN_SetBoardLEDColor(LEFT , YELLOW);
  CoRoSoN_SetBoardLEDColor(RIGHT, YELLOW);
  delay(200);
  CoRoSoN_SetBoardLEDColor(LEFT , BLUE);
  CoRoSoN_SetBoardLEDColor(RIGHT, BLUE);
  delay(200);
  CoRoSoN_SetBoardLEDColor(LEFT , CYAN);
  CoRoSoN_SetBoardLEDColor(RIGHT, CYAN);
  delay(200);
  CoRoSoN_SetBoardLEDColor(LEFT , MAGENTA);
  CoRoSoN_SetBoardLEDColor(RIGHT, MAGENTA);
  delay(200);
  CoRoSoN_SetBoardLEDColor(LEFT , WHITE);
  CoRoSoN_SetBoardLEDColor(RIGHT, WHITE);
  delay(200);
  CoRoSoN_SetBoardLEDColor(LEFT , OFF);
  CoRoSoN_SetBoardLEDColor(RIGHT, OFF);
}

bool lightbarrierTriggered() {
  return (analogRead(ANALOG_IN_4) > 1000);
}

void drive(int speed, int rotation) {
  int MaxSpeed = ABS(speed) + ABS(rotation);
  if (MaxSpeed > 100) {
    speed = (speed * 100) / MaxSpeed;
    rotation = (rotation * 100) / MaxSpeed;
  }
  int spd1 = rotation - speed;
  int spd2 = rotation + speed;
  DIRECTION dir1 = (spd1 >= 0 ? FORWARD : BACKWARD);
  DIRECTION dir2 = (spd2 >= 0 ? FORWARD : BACKWARD);
  CoRoSoN_SetMotor(MOTOR_1, dir1, spd1);
  CoRoSoN_SetMotor(MOTOR_2, dir2, spd2);
}  

void standby() {
  //
  // Status LED Lightbarrier
  //
  if (lightbarrierTriggered()) {
    CoRoSoN_SetBoardLEDColor(RIGHT, GREEN);
  } else {
    CoRoSoN_SetBoardLEDColor(RIGHT, OFF);
  }
  //
  // Status LED ball
  //
  if (irRing.BallSeen()) {
    if (ABS(irRing.BallDirection()) < 3) {
      CoRoSoN_SetBoardLEDColor(LEFT, GREEN);
    } else if (ABS(irRing.BallDirection()) < 10) {
      CoRoSoN_SetBoardLEDColor(LEFT, CYAN);
    } else {
      CoRoSoN_SetBoardLEDColor(LEFT, BLUE);
    }
  } else {
    CoRoSoN_SetBoardLEDColor(LEFT, RED);
  }
  //
  // Button left => drive test
  //
  if (CoRoSoN_ButtonIsPressed(I2C_MODULE_1, LEFT)) {
    drive(50, 0);
  } else {
    drive(0, 0);
  }
  //
  // Button right => enter game
  //
  CoRoSoN_SetI2CLEDColor(I2C_MODULE_1, RIGHT, GREEN);
  if (CoRoSoN_ButtonIsPressed(I2C_MODULE_1, RIGHT)) {
    if (buttonDeadTime > 500) {
      IsInGame = true;
      buttonDeadTime = 0;
    }
  }
}

void game() {
  //
  // Shut off all LEDs
  //
  CoRoSoN_SetBoardLEDColor(RIGHT, OFF);
  CoRoSoN_SetI2CLEDColor(I2C_MODULE_1, LEFT, OFF);
  CoRoSoN_SetI2CLEDColor(I2C_MODULE_1, RIGHT, OFF);
  //
  // Game strategy
  //
  /*
    TODO: Insert your game strategy...
  */
}

void loop() {
  if (IsInGame) {
    game();
    //
    // Button right => enter game
    //
    if (CoRoSoN_ButtonIsPressed(I2C_MODULE_1, LEFT) || CoRoSoN_ButtonIsPressed(I2C_MODULE_1, RIGHT)) {
      if (buttonDeadTime > 500) {
        IsInGame = false;
        buttonDeadTime = 0;
        CoRoSoN_SetMotor(MOTOR_4, FORWARD, 0);
      }
    }
  } else {
    standby();
  }
  //
  // Debug prints
  //
  DEBUG_PRINT(irRing.BallSeen());
  DEBUG_PRINT(irRing.BallDirection());
  DEBUG_PRINT(irRing.BallDistance());
  DEBUG_PRINT(pixy.GoalSeen());
  DEBUG_PRINT(pixy.GoalDirection());
  DEBUG_PRINT(pixy.OwnGoalSeen());
  DEBUG_PRINT(pixy.OwnGoalDirection());
  //
  // Update
  //
  irRing.Update();
  pixy.Update();
  delay(5);
}
